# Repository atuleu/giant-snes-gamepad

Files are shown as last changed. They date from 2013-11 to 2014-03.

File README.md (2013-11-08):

# giant-snes-gamepad #

This project aims to build a Giant Super Nintendo Gamepad USB
gamepad. This repository will aim to host all instructions and how to
build and use it, as well as source code.

The idea is to construct a foot step platform were two people have to
play cooperatively on one gamepad.

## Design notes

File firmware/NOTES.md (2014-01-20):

# Notes

This file keep some useful conceptions notes.

## Analog to Digital COnversion

### Prescaling and window size selection

The analog input are multiplexed around a single ADC converter. Therefore one convertion a time could occurs

We should choose a prescaler for the clock. BAsed on the XTAL (16MHz) to be between 50 kHz and 200 kHz. Only possible values is 128, and gave us a ADC clock rate of 125 kHz.

First conversiona after ADEN is set takes 25 clock cycle 13 afterwards.

We would like to know the power of two that gives us the best window size to filter the read data. We would like to have a 100 Hz sensor

We have ( 4 * 13 ) * 128 / 16e6 * 12 = 4.99 ms

And ( 8 * 13 ) * 128 / 16e6 * 12 = 9.98 ms.

We choose the later, and we perform updates every 12 ms to the computer (80 Hz controller )

### notes

* channel change can only occurs safely :
  a. When ADATE or ADEN is cleared.
  b. During conversion, minimum one ADC clock cycle after the trigger event.
  c. After a conversion, before the interrupt flag used as trigger source is cleared.

* From the schematics, we have a cleaning capacitor on AVRef, so the default setting would be the best. ( Internal connection to AVcc with Noise cancellation cap on AVref )

* ADEN should be left to 1. Then only start with ADSC.

* Interrupt vector maybe called ADC_vect

* Beware of order where results are read. refer to doc !

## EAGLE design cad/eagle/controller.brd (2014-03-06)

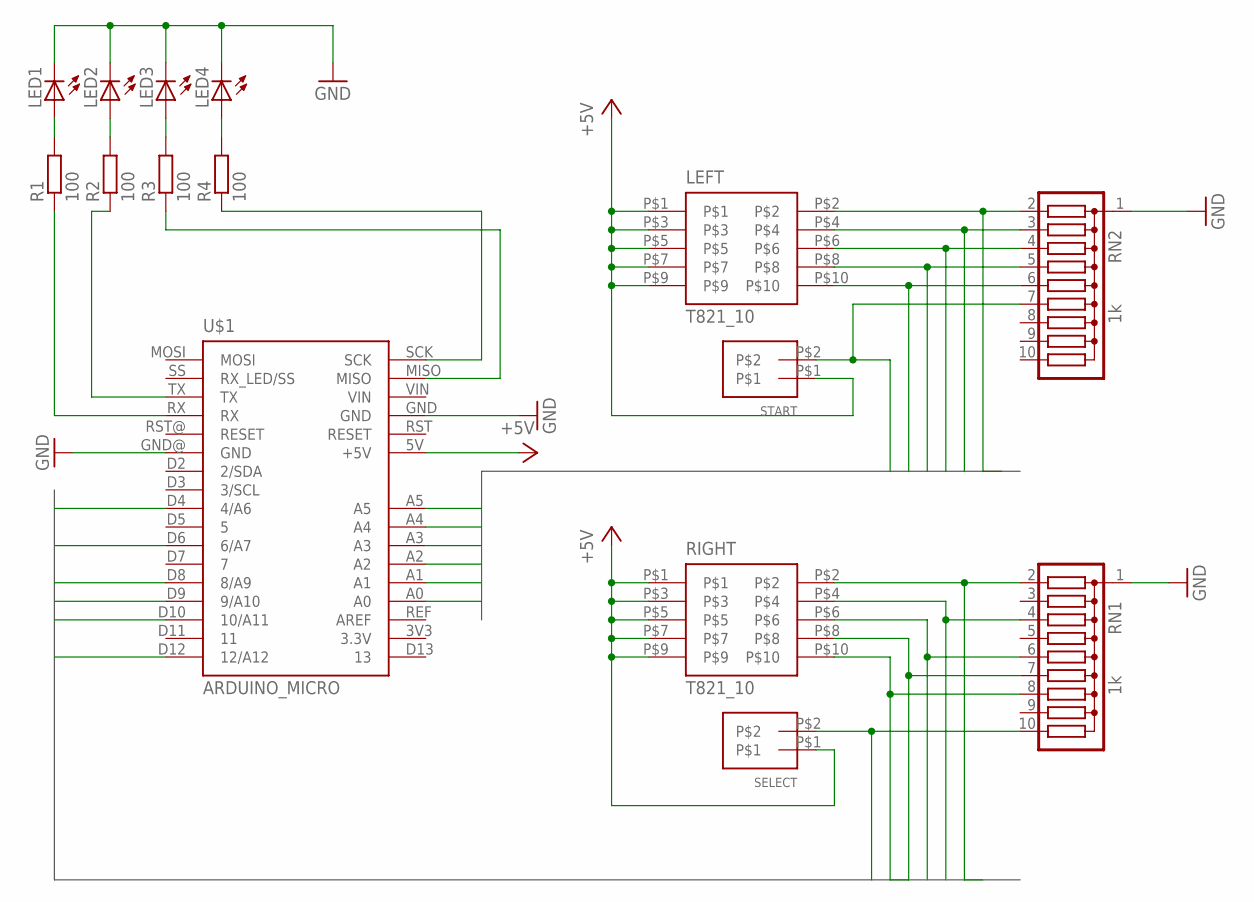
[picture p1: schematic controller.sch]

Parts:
LED1, LED2, LED3, LED4: LED5MM
LEFT: T821_10
R1, R2, R3, R4: 100; 0204/7
RIGHT: T821_10
RN1, RN2: 1k; SIL10
SELECT: 100MIL_2POS
START: 100MIL_2POS
U$1: ARDUINO_MICRO

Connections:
+5V: LEFT.P$1, LEFT.P$3, LEFT.P$5, LEFT.P$7, LEFT.P$9, RIGHT.P$1, RIGHT.P$3, RIGHT.P$5, RIGHT.P$7, RIGHT.P$9, SELECT.P$1, START.P$1, U$1.5V (+5V)
B0: LEFT.P$2, RN2.2, U$1.A0
B1: LEFT.P$4, RN2.3, U$1.A1
B2: LEFT.P$6, RN2.4, U$1.A2
B3: LEFT.P$8, RN2.5, U$1.A3
B4: LEFT.P$10, RN2.6, U$1.A4
B5: RN2.7, START.P$2, U$1.A5
B6: RIGHT.P$2, RN1.2, U$1.D4 (4/A6)
B7: RIGHT.P$4, RN1.4, U$1.D6 (6/A7)
B8: RIGHT.P$6, RN1.6, U$1.D8 (8/A9)
B9: RIGHT.P$8, RN1.7, U$1.D9 (9/A10)
B10: RIGHT.P$10, RN1.8, U$1.D10 (10/A11)
B11: RN1.10, SELECT.P$2, U$1.D12 (12/A12)
GND: LED1.K (C), LED2.K (C), LED3.K (C), LED4.K (C), RN1.1, RN2.1, U$1.GND, U$1.GND@ (GND)
unnamed: LED1.A, R1.2
unnamed: LED2.A, R2.2
unnamed: LED3.A, R3.2
unnamed: LED4.A, R4.2
unnamed: R1.1, U$1.RX
unnamed: R2.1, U$1.TX
unnamed: R4.1, U$1.SCK
unnamed: R3.1, U$1.MISO

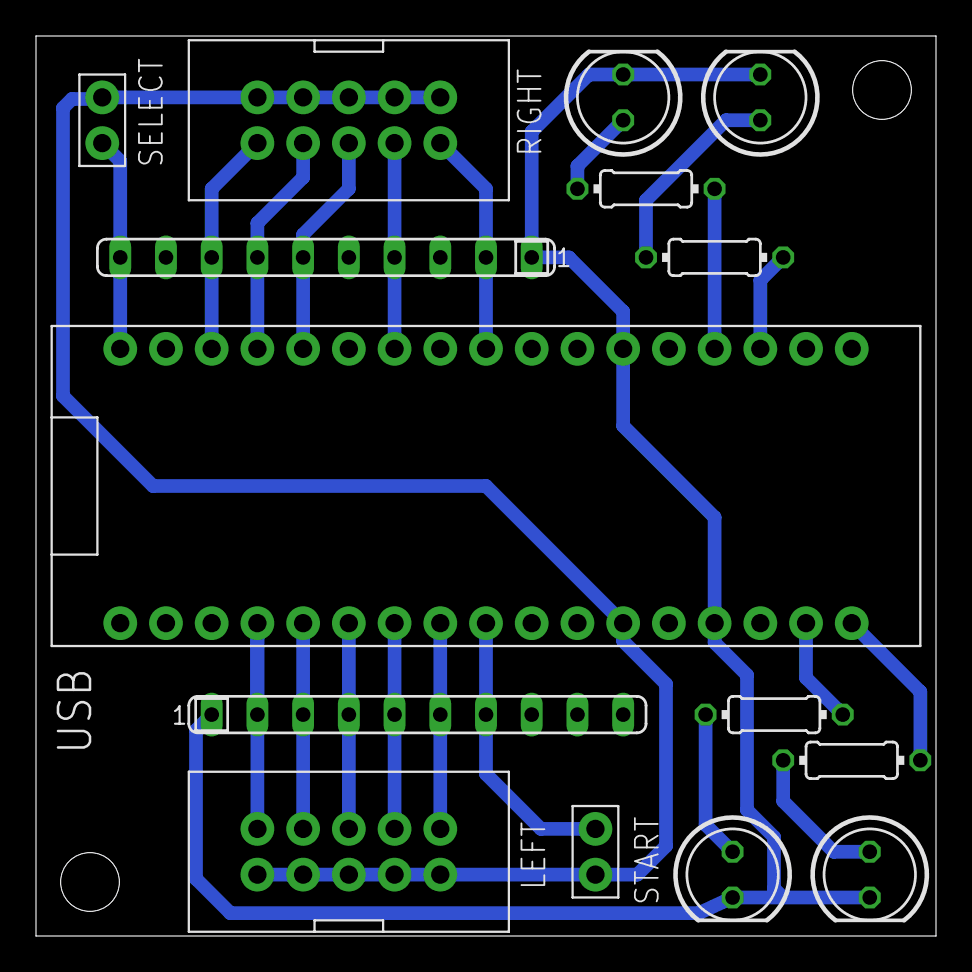
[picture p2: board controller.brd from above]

Board: 2 copper layers, 50.0 x 50.0 mm, 15 parts (0 on the bottom side), 22 nets.

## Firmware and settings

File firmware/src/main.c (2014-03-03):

#include <avr/io.h> 
#include <avr/power.h>
#include <avr/wdt.h>


#include "Systime.h"
#include "Gamepad.h"
#include "USB.h"

void SetupHardware() {
	// Bootloader workaround testing. 
	// 
	// Datasheet says that to power off the USB interface we have to do 'some' of: 
	//       Detach USB interface 
	//      Disable USB interface 
	//      Disable PLL 
	//      Disable USB pad regulator 

	// Disable the USB interface 
	USBCON &= ~(1 << USBE); 
    
	// Disable the VBUS transition enable bit 
	USBCON &= ~(1 << VBUSTE); 
    
	// Disable the VUSB pad 
	USBCON &= ~(1 << OTGPADE); 
    
	// Freeze the USB clock 
	USBCON &= ~(1 << FRZCLK); 
    
	// Disable USB pad regulator 
	UHWCON &= ~(1 << UVREGE); 
    
	// Clear the IVBUS Transition Interrupt flag 
	USBINT &= ~(1 << VBUSTI); 
    
	// Physically detact USB (by disconnecting internal pull-ups on D+ and D-) 
	UDCON |= (1 << DETACH); 

	//Arduino's micro bootloader let the USB interrupt on, but if we
	//are not using USB, well it blows our face because ISR routine
	//are not there. We disable the interrupt. Maybe a USB clock
	//freeze will be great too. This is teh first step because we do
	//not want our USB host to wake and crash us.

	//	UDIEN &= ~(_BV(SUSPE) | _BV(EORSTE) );

	//this is not stricly needed as set by Arduino Micro's
	//bootloader. But just to be absolutely certain :

	MCUSR &= ~_BV(WDRF); // clear watchdog flag
	wdt_disable(); //disbale it
	
	//no prescale of F_CPU
	clock_prescale_set(clock_div_1);

	//rest of the init here

	_delay_ms(20);
	
	InitUSB();	

	InitSystime();

	InitGamepad();




	//we need to start ADC here !
	ADCSRA |= _BV(ADEN);
	ADCSRA |= _BV(ADSC);
	
}



#define LOOP_IN_MS 1000

int main (void) { 
	SetupHardware();

	while(1) {
		//highest priority to USB
		ProcessUSB();

		ProcessGamepad();

	}
}
 

//ISR(USB_COM_vect){}
//ISR(USB_GEN_vect){}

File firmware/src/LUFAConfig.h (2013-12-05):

/*
             LUFA Library
     Copyright (C) Dean Camera, 2013.

  dean [at] fourwalledcubicle [dot] com
           www.lufa-lib.org
*/

/*
  Copyright 2013  Dean Camera (dean [at] fourwalledcubicle [dot] com)

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
  The author disclaims all warranties with regard to this
  software, including all implied warranties of merchantability
  and fitness.  In no event shall the author be liable for any
  special, indirect or consequential damages or any damages
  whatsoever resulting from loss of use, data or profits, whether
  in an action of contract, negligence or other tortious action,
  arising out of or in connection with the use or performance of
  this software.
*/

/** \file
 *  \brief LUFA Library Configuration Header File (Template)
 *
 *  This is a header file which can be used to configure LUFA's
 *  compile time options, as an alternative to the compile time
 *  constants supplied through a makefile. To use this configuration
 *  header, copy this into your project's root directory and supply
 *  the \c USE_LUFA_CONFIG_HEADER token to the compiler so that it is
 *  defined in all compiled source files.
 *
 *  For information on what each token does, refer to the LUFA
 *  manual section "Summary of Compile Tokens".
 */

#ifndef __LUFA_CONFIG_H__
#define __LUFA_CONFIG_H__

	#if (ARCH == ARCH_AVR8)

		/* Non-USB Related Configuration Tokens: */
//		#define DISABLE_TERMINAL_CODES

		/* USB Class Driver Related Tokens: */
//		#define HID_HOST_BOOT_PROTOCOL_ONLY
//		#define HID_STATETABLE_STACK_DEPTH       {Insert Value Here}
//		#define HID_USAGE_STACK_DEPTH            {Insert Value Here}
//		#define HID_MAX_COLLECTIONS              {Insert Value Here}
//		#define HID_MAX_REPORTITEMS              {Insert Value Here}
//		#define HID_MAX_REPORT_IDS               {Insert Value Here}
//		#define NO_CLASS_DRIVER_AUTOFLUSH

		/* General USB Driver Related Tokens: */
//		#define ORDERED_EP_CONFIG
#define USE_STATIC_OPTIONS               (USB_DEVICE_OPT_FULLSPEED | USB_OPT_REG_ENABLED | USB_OPT_AUTO_PLL)
#define USB_DEVICE_ONLY
//		#define USB_HOST_ONLY
//		#define USB_STREAM_TIMEOUT_MS            {Insert Value Here}
//		#define NO_LIMITED_CONTROLLER_CONNECT
		#define NO_SOF_EVENTS

		/* USB Device Mode Driver Related Tokens: */
		#define USE_RAM_DESCRIPTORS
//      #define USE_FLASH_DESCRIPTORS
//		#define USE_EEPROM_DESCRIPTORS
//		#define NO_INTERNAL_SERIAL
		#define FIXED_CONTROL_ENDPOINT_SIZE      8
		#define DEVICE_STATE_AS_GPIOR            0
		#define FIXED_NUM_CONFIGURATIONS         1
//		#define CONTROL_ONLY_DEVICE
//		#define INTERRUPT_CONTROL_ENDPOINT
//		#define NO_DEVICE_REMOTE_WAKEUP
		#define NO_DEVICE_SELF_POWER

		/* USB Host Mode Driver Related Tokens: */
//		#define HOST_STATE_AS_GPIOR              0
//		#define USB_HOST_TIMEOUT_MS              {Insert Value Here}
//		#define HOST_DEVICE_SETTLE_DELAY_MS	     {Insert Value Here}
//		#define NO_AUTO_VBUS_MANAGEMENT
//		#define INVERTED_VBUS_ENABLE_LINE

	#elif (ARCH == ARCH_XMEGA)

		/* Non-USB Related Configuration Tokens: */
//		#define DISABLE_TERMINAL_CODES

		/* USB Class Driver Related Tokens: */
//		#define HID_HOST_BOOT_PROTOCOL_ONLY
//		#define HID_STATETABLE_STACK_DEPTH       {Insert Value Here}
//		#define HID_USAGE_STACK_DEPTH            {Insert Value Here}
//		#define HID_MAX_COLLECTIONS              {Insert Value Here}
//		#define HID_MAX_REPORTITEMS              {Insert Value Here}
//		#define HID_MAX_REPORT_IDS               {Insert Value Here}
//		#define NO_CLASS_DRIVER_AUTOFLUSH

		/* General USB Driver Related Tokens: */
//		#define USE_STATIC_OPTIONS               {Insert Value Here}
//		#define USB_STREAM_TIMEOUT_MS            {Insert Value Here}
//		#define NO_LIMITED_CONTROLLER_CONNECT
//		#define NO_SOF_EVENTS

		/* USB Device Mode Driver Related Tokens: */
//		#define USE_RAM_DESCRIPTORS
		#define USE_FLASH_DESCRIPTORS 1
//		#define USE_EEPROM_DESCRIPTORS
//		#define NO_INTERNAL_SERIAL
//		#define FIXED_CONTROL_ENDPOINT_SIZE      {Insert Value Here}
//		#define DEVICE_STATE_AS_GPIOR            {Insert Value Here}
//		#define FIXED_NUM_CONFIGURATIONS         {Insert Value Here}
//		#define CONTROL_ONLY_DEVICE
// 		#define MAX_ENDPOINT_INDEX               {Insert Value Here}
//		#define NO_DEVICE_REMOTE_WAKEUP
//		#define NO_DEVICE_SELF_POWER

	#elif (ARCH == ARCH_UC3)

		/* Non-USB Related Configuration Tokens: */
//		#define DISABLE_TERMINAL_CODES

		/* USB Class Driver Related Tokens: */
//		#define HID_HOST_BOOT_PROTOCOL_ONLY
//		#define HID_STATETABLE_STACK_DEPTH       {Insert Value Here}
//		#define HID_USAGE_STACK_DEPTH            {Insert Value Here}
//		#define HID_MAX_COLLECTIONS              {Insert Value Here}
//		#define HID_MAX_REPORTITEMS              {Insert Value Here}
//		#define HID_MAX_REPORT_IDS               {Insert Value Here}
//		#define NO_CLASS_DRIVER_AUTOFLUSH
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

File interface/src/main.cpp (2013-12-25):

#include "MainWindow.h"

#include <iostream>
#include <exception>


#include <glog/logging.h>



int main(int argc, char ** argv) {
	FLAGS_logtostderr = true;
	FLAGS_colorlogtostderr = true;
	// Initialize Google's logging library.
	google::InitGoogleLogging(argv[0]);


	QApplication application(argc,argv);

	MainWindow main;
	main.show();

	return application.exec();
}

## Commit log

2013-11-09 Adds arduino-cmake submodule
2013-12-01 Updates to use my head of arduino cmake
2013-12-01 Updates to head of atuleu/arduino-cmake
2013-12-01 LUFAs skeleton for a HID device
2013-12-02 Points to atuleu's fork arduino-cmake
2013-12-02 Reconfigures device to use bulk endpoint
2013-12-03 Sets a basic timer loop
2013-12-05 Makes the USB device beeing recognized on OS X and linux
2013-12-05 Adds back bulk control endpoint
    They will be usefull for device calibration. Solves also a problem
    where device was not automatically detected, due to a lack of wakeup
    instructions.
    [LUFAConfig.h]
2013-12-05 Adds two input buttons
2013-12-10 Go skeleton for drivers
2013-12-11 Adds listing and opening of usb device
2013-12-14 Switches to C++
    Go need a go.usb
2013-12-14 Replaces output to stderr by logging
    [main.cpp]
2013-12-14 Makes Darwin workaround platform specific
    Due to this upstream bug ( http://www.libusb.org/ticket/171 )
    libusb_get_active_config_descriptor() segfault if the device is not
    libusb_open before. This patch address this issue for OS X only, and
    let the device in a closed state after construction (like other
    platforms).
2013-12-14 Try to fetch some data from the device
2013-12-21 Implements Gamepad::ReadAllParams() for device
2013-12-22 Implements host side communication all thread safe
2014-01-20 Adds some notes about ADC
2014-01-24 Sets a 12 channel ADC
2014-02-27 Adds a Save in EEPROM button
2014-02-27 Adds a timer for scanning devices
2014-03-03 Adds LEDs display
2014-03-03 Insures devices always keep same address
2014-03-03 Adds device error reporting through LEDs;
    [Gamepad.c]
2014-03-03 Corrects the report of count number
    [Gamepad.c]
2014-03-03 Remaps the pin
2014-03-06 Corrects a count read out bug
    [Gamepad.c]
2014-03-06 Adds schematics and PCB for the controller board
    [controller.brd, controller.sch]
2014-03-06 new version *
    [controller.brd, controller.sch]
